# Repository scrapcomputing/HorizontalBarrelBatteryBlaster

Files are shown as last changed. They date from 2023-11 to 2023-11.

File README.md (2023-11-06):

# Horizontal Barrel Battery Blaster

Horizontal Barrel Battery Blaster is a small PCB for replacing an old rechargeable barrel-type CMOS batteries with a non-rechargeable CR2032 Lithium battery.
Such barrel batteries were quite common on vintage computer motherboards up until the 486 era.
These barrel batteries tend to leak, damaging the motherboard and the surrounding components.

Unlike the [Barrel Battery Blaster](https://github.com/scrapcomputing/BarrelBatteryBlaster) and the [Vertical Battery Blaster](https://github.com/scrapcomputing/VerticalBarrelBatteryBlaster) this board sits horizontally on the motherboard.

> **Warning**
> There may not be enough clearance on your motherboard for this board and the CR2032 holder. So please check!

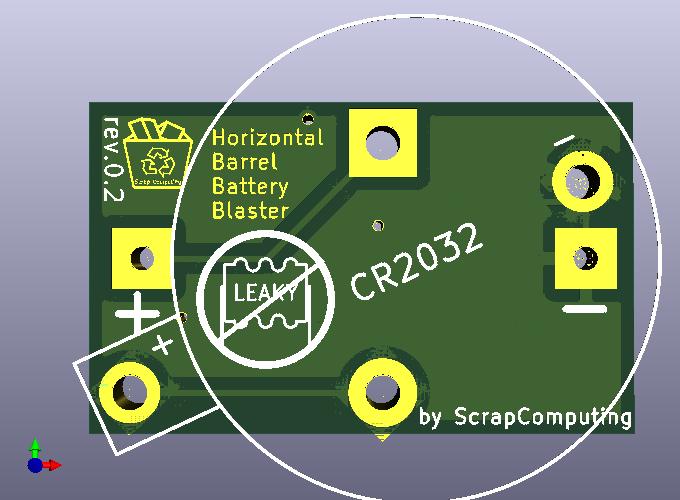
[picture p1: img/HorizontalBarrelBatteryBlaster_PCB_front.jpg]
Horizontal Barrel Battery Blaster PCB Front

<p float="left">
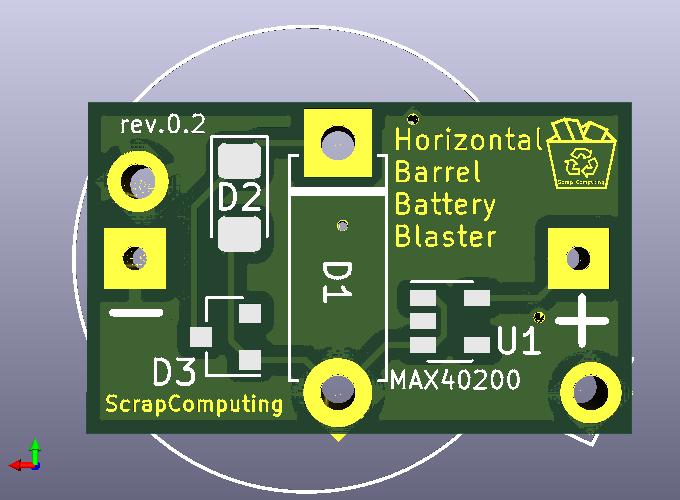
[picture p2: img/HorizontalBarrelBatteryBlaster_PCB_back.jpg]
Horizontal Barrel Battery Blaster PCB Back

</p>
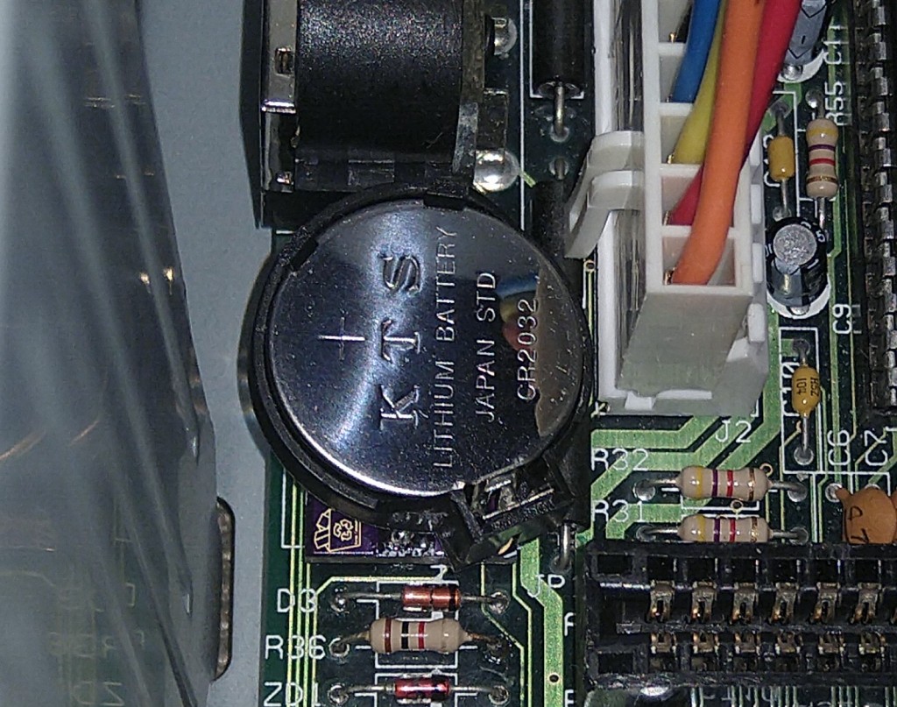
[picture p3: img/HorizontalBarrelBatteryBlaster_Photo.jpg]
Horizontal Barrel Battery Blaster Photo


# Features
- Uses a standard through-hole CR2032 battery holder of the horizontal type
- Accepts 3 types of diode footprints: through-hole (e.g., 1N5817), 1206 and SOT23 ANK (e.g., BAS40-04)
- Rev.0.2. includes solder pads for a MAX40200 SOT23-5 ideal diode. This is great for older systems that need as little voltage drop as possible.

# Video
https://www.youtube.com/watch?v=v_9UKSxLt-k

# Similar Projects
- [Vertical Battery Blaster](https://github.com/scrapcomputing/VerticalBarrelBatteryBlaster)
- [Barrel Battery Blaster](https://github.com/scrapcomputing/BarrelBatteryBlaster)
- [Not-A-Varta](https://github.com/wiretap-retro/Not-A-Varta-CR2032)

# How can I get one?

You can order one at your PCB fab of choice.
The simplest way is to use the zipped gerber file found in the [releases](https://github.com/scrapcomputing/HorizontalBarrelBatteryBlaster/releases).

# Bill of materials

Item                                             | #   | Description
-------------------------------------------------|-----|-----------------------------------------
Pins out of an male header (usually 2.54mm pitch)| 2   | For connecting the BarrelBatteryBlaster to the motherboard
Horizontally mounted CR2032 battery holder       | 1   | For the CR2032 Lithium battery
Diode or Ideal diode                             | 1   | Through-hole (e.g., 1N5817) or 1206 or SOT23 ANK (current flows pin1 -> pin3 like in BAS40 or BAS40-04) or MAX40200 SOT23-5 ideal didoe

# Changelist
rev.0.1: Original revision 
rev.0.2: Adds solder pads for MAX40200 ideal diode

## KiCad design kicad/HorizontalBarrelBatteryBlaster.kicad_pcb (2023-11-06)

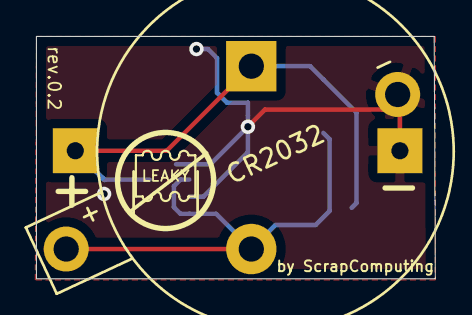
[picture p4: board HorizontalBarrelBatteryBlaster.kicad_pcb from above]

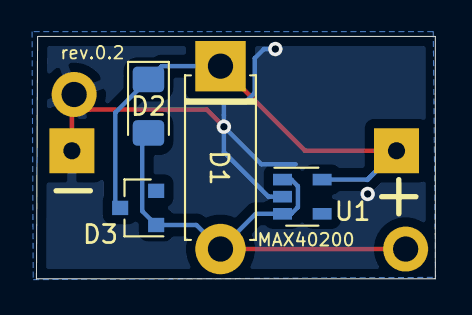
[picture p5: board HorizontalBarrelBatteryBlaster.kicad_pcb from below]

Board: 2 copper layers, 22.2 x 13.5 mm, 6 parts (5 on the bottom side), 3 nets.

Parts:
BarrelBattery1: BarrelBattery; BarrelBattery_pads
CR2032: CR2032; CR2032_battery_holder
D1: D_Schottky; D_5W_P10.16mm_Horizontal
D2: D_Schottky; D_1206_3216Metric_Pad1.42x1.75mm_HandSolder
D3: D_Schottky; D_SOT-23_ANK
U1: MAX40200AUK; SOT-23-5

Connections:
/3V: CR2032.1, D1.2, D2.2, D3.2, U1.1, U1.3
GND: BarrelBattery1.2, CR2032.2, U1.2
unnamed: BarrelBattery1.1, D1.1, D2.1, D3.1, U1.5
